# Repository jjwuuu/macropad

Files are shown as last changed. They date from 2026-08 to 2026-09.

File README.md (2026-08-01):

## Bill of Materials
### Required
 - 1x Seeed Studio XIAO RP2040
 - 6x MX hotswap sockets
 - 7x 1N4148 small signal diodes
 - 1x EC11 rotary encoder with push button
 - 4x M3x12 screws (support M3x8 - M3x14) 
 
## Assembly Instructions 

1. 3D print the top case, bottom case, and knob. For the best results, print the top case and bottom case with 100% infill.
2. Solder the hotswap sockets and diodes, taking note of the polarity. 
3. Solder the microcontroller, using pin headers to align the pads but not soldering the pin headers.
4. Solder the rotary encoder on the opposite side of the board as the rest of the components.
5. Press and hold the BOOT button on the microcontroller. Then, while still holding the button, plug in the microcontroller to a computer. The microcontroller should appear as a virtual USB storage device.
6. Upload the .uf2 firmware file to the microcontroller. The virtual USB storage device should disconnect once flashed.
7. Unplug and replug the USB cable.
8. Test that the keys work by inserting switches into the hotswap sockets and depressing them. The keys should type the numbers 1-6 by default.
9. Test that the rotary encoder works by rotating it and pressing it. The encoder should control volume when rotated and type the number 7 when pressed.
10. Unplug the USB cable.
11. Insert the completed PCB into the bottom case, slotting in the USB conector first.
12. Place the top case on top of the bottom case.
13. Secure the bottom case to the top case with the M3x12 screws or the printable pegs/rivets.
14. Insert the switches into the top case. The switches should securely slot into the hotswap sockets.
15. Attach the keycaps and knob to the key switches and rotary encoder.
16. Connect the USB cable.
17. Open the [VIA app](https://www.usevia.app/).
18. Go to the "Settings" tab and enable "Show Design tab".
19. Go to the "Design" tab and upload the .json file.
20. Go to the "Configure" tab. After authorizing the device, the macropad is now configurable!

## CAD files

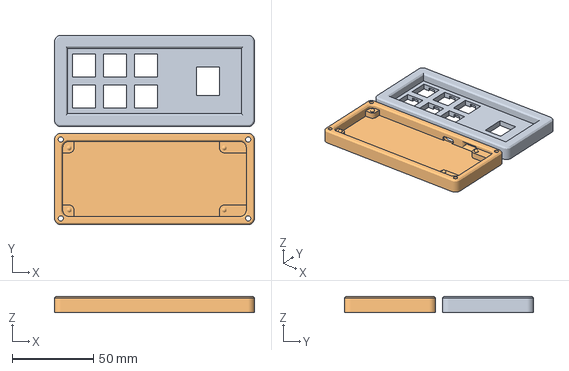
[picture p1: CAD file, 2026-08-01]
Case/workshopcase.3mf
122.8 x 116.2 x 10.0 mm
bottom_case-Body001
bottom_case-Body

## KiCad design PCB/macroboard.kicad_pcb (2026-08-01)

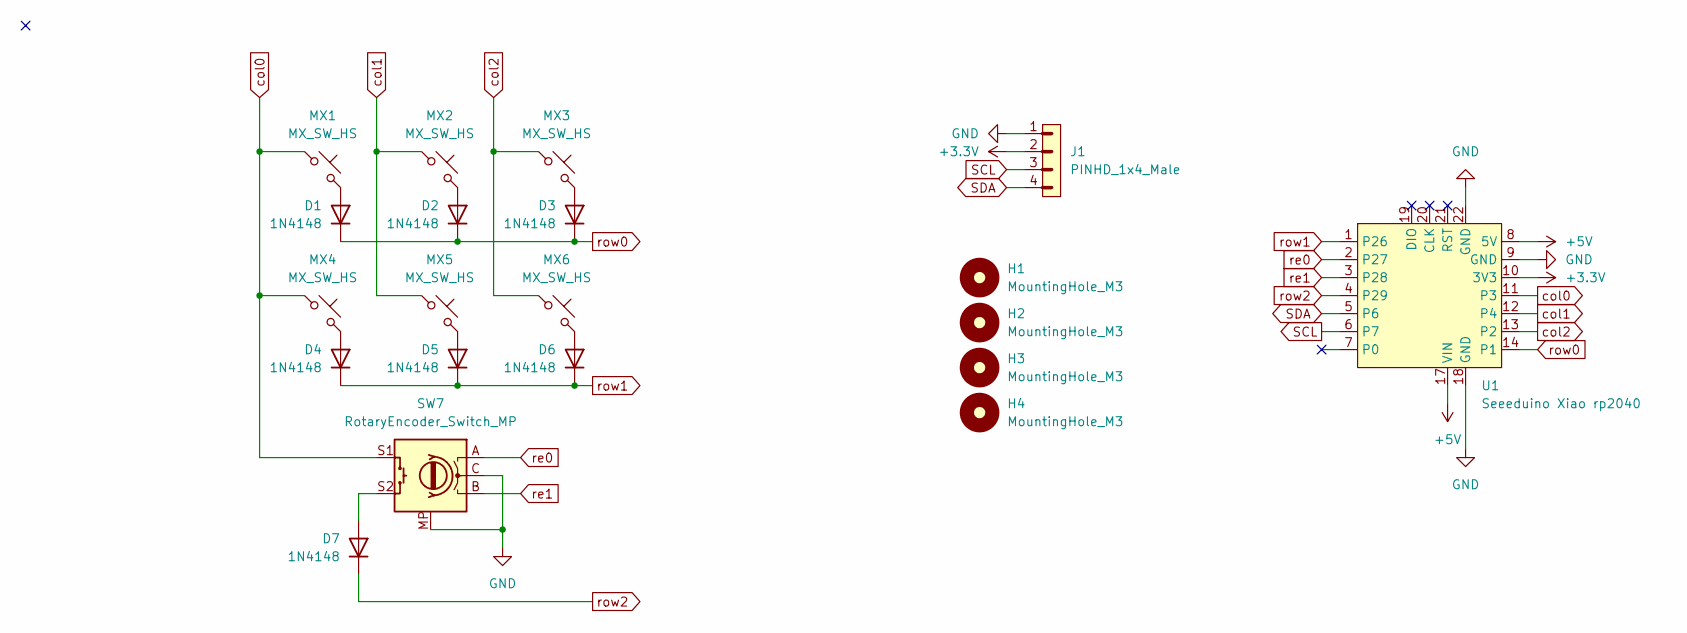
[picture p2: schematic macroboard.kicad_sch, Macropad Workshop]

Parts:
D1, D2, D3, D4, D5, D6, D7: 1N4148; D_DO-35_SOD27_P7.62mm_Horizontal_Hybrid
H1, H2, H3, H4: MountingHole_M3; MountingHole_3.2mm_M3_Pad
J1: PINHD_1x4_Male; PinHeader_1x04_P2.54mm_Horizontal
MX1, MX2, MX3, MX4, MX5, MX6: MX_SW_HS; SW_MX_HS_CPG151101S11_1u
SW7: RotaryEncoder_Switch_MP; ROT_Alps_EC11E-Switch
U1: Seeeduino Xiao rp2040; Xiao_rp2040_ACH

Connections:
+3.3V: J1.2, U1.10 (3V3)
+5V: U1.8 (5V), U1.17 (VIN)
GND: J1.1, SW7.C, SW7.MP, U1.9 (GND), U1.18 (GND), U1.22 (GND)
unnamed: D1.2 (A), MX1.2
unnamed: D2.2 (A), MX2.2
unnamed: D3.2 (A), MX3.2
unnamed: D4.2 (A), MX4.2
unnamed: D5.2 (A), MX5.2
unnamed: D6.2 (A), MX6.2
unnamed: D7.2 (A), SW7.S2
RGB: U1.7 (P0)
SCL: J1.3, U1.6 (P7)
SDA: J1.4, U1.5 (P6)
col0: MX1.1, MX4.1, SW7.S1, U1.11 (P3)
col1: MX2.1, MX5.1, U1.12 (P4)
col2: MX3.1, MX6.1, U1.13 (P2)
re0: SW7.A, U1.2 (P27)
re1: SW7.B, U1.3 (P28)
row0: D1.1 (K), D2.1 (K), D3.1 (K), U1.14 (P1)
row1: D4.1 (K), D5.1 (K), D6.1 (K), U1.1 (P26)
row2: D7.1 (K), U1.4 (P29)

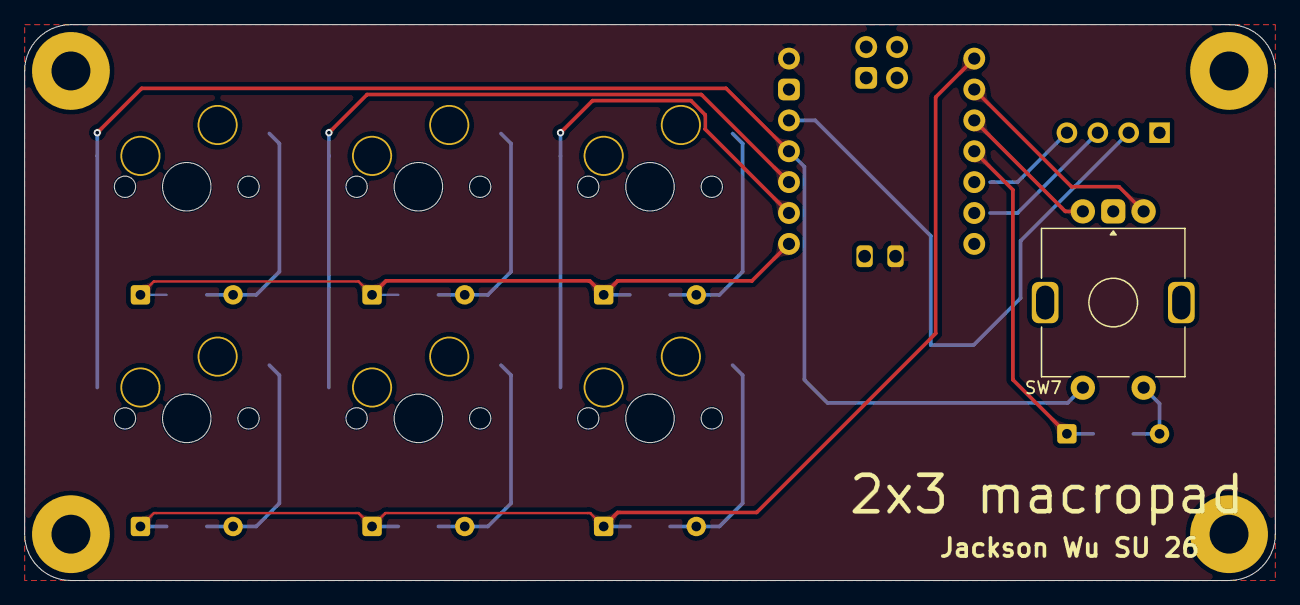
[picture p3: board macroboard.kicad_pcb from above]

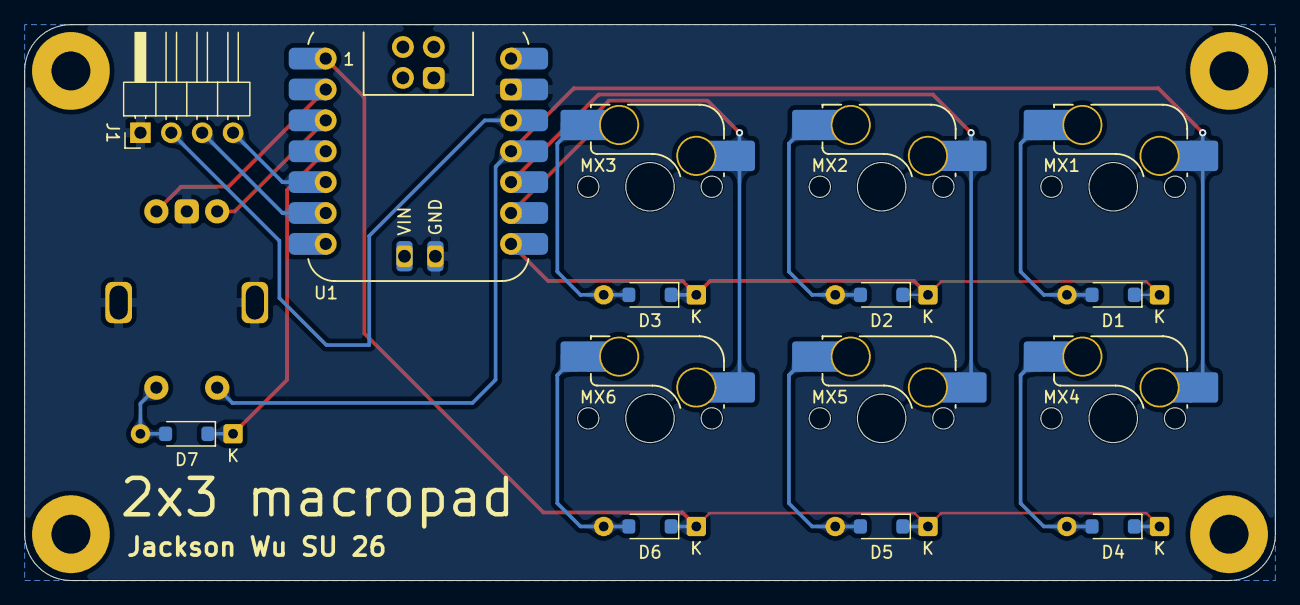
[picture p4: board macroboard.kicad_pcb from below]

Board: 2 copper layers, 102.9 x 45.7 mm, 20 parts (15 on the bottom side), 20 nets.

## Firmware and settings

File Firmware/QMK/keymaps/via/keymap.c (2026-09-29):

#include QMK_KEYBOARD_H

enum custom_keycodes {
    CYCLE_LAYERS = QK_KB_0
};

bool process_record_user(uint16_t keycode, keyrecord_t *record) {
    if (keycode == CYCLE_LAYERS && record->event.pressed) {
        uint8_t current_layer = get_highest_layer(layer_state);
        layer_move((current_layer + 1) % 6);
        return false;
    }

    return true;
}

const rgblight_segment_t PROGMEM layer0_lighting[] = RGBLIGHT_LAYER_SEGMENTS({0, 1, HSV_BLUE});
const rgblight_segment_t PROGMEM layer1_lighting[] = RGBLIGHT_LAYER_SEGMENTS({1, 1, HSV_RED});
const rgblight_segment_t PROGMEM layer2_lighting[] = RGBLIGHT_LAYER_SEGMENTS({2, 1, HSV_GREEN});
const rgblight_segment_t PROGMEM layer3_lighting[] = RGBLIGHT_LAYER_SEGMENTS({3, 1, HSV_PURPLE});
const rgblight_segment_t PROGMEM layer4_lighting[] = RGBLIGHT_LAYER_SEGMENTS({4, 1, HSV_ORANGE});
const rgblight_segment_t PROGMEM layer5_lighting[] = RGBLIGHT_LAYER_SEGMENTS({5, 1, HSV_CYAN});

const rgblight_segment_t *const PROGMEM rgb_layers[] = RGBLIGHT_LAYERS_LIST(
    layer0_lighting,
    layer1_lighting,
    layer2_lighting,
    layer3_lighting,
    layer4_lighting,
    layer5_lighting
);

void keyboard_post_init_user(void) {
    rgblight_layers = rgb_layers;
}

layer_state_t layer_state_set_user(layer_state_t state) {
    uint8_t layer = get_highest_layer(state);

    for (uint8_t i = 0; i < 6; i++) {
        rgblight_set_layer_state(i, layer == i);
    }

    return state;
}

const uint16_t PROGMEM keymaps[][MATRIX_ROWS][MATRIX_COLS] = {
    [0] = LAYOUT(
        CYCLE_LAYERS, KC_2, KC_3,
        KC_4,    KC_5,    KC_6,
        KC_7
    ),
    [1] = LAYOUT(
        _______, _______, _______,
        _______, _______, _______,
        _______
    ),
    [2] = LAYOUT(
        _______, _______, _______,
        _______, _______, _______,
        _______
    ),
    [3] = LAYOUT(
        _______, _______, _______,
        _______, _______, _______,
        _______
    ),
    [4] = LAYOUT(
        _______, _______, _______,
        _______, _______, _______,
        _______
    ),
    [5] = LAYOUT(
        _______, _______, _______,
        _______, _______, _______,
        _______
    )
};

#if defined(ENCODER_MAP_ENABLE)
const uint16_t PROGMEM encoder_map[][NUM_ENCODERS][NUM_DIRECTIONS] = {
    [0] = { ENCODER_CCW_CW(KC_VOLD, KC_VOLU) },
    [1] = { ENCODER_CCW_CW(_______, _______) },
    [2] = { ENCODER_CCW_CW(_______, _______) },
    [3] = { ENCODER_CCW_CW(_______, _______) },
    [4] = { ENCODER_CCW_CW(_______, _______) },
    [5] = { ENCODER_CCW_CW(_______, _______) }
};
#endif
